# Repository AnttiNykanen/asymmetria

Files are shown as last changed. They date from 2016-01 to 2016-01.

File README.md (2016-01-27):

# ESP8266-based LED dimmer #

This dimmer designed to fit inside a Lival Asymmetria desk lamp. The
plan is to use [LED strips like these][ledstrips] to replace the stock
fluorescent bulb, but other kinds of LEDs should work too, as long as
you adjust the shunt resistor accordingly and don't exceed the 3.3V
regulator's ratings.

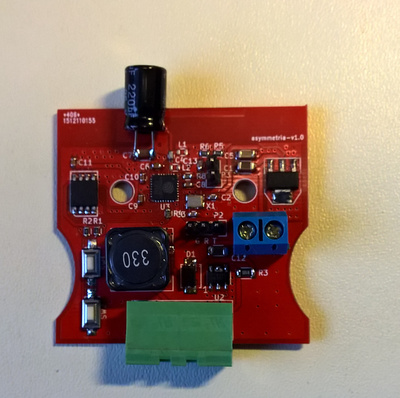
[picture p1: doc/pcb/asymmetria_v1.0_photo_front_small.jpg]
pcb photo


## Contents of this directory ##

  * [hardware](./hardware/): Hardware design files
  * [firmware](./firmware/): Firmware source code
  * [doc](./doc/): Documentation
  
## License ##

  * Hardware:
    [CC BY-SA 4.0](https://creativecommons.org/licenses/by-sa/4.0/)
  * Firmware:
    * Files in the user subdirectory:
      [ISC](https://opensource.org/licenses/ISC)
    * Everything else: whatever the files say
 
## The Fine Print ##

Note that owning and/or using homemade radio transmitters, which this thing is, might not be legal for everyone everywhere.

[ledstrips]: http://www.aliexpress.com/item/Ultra-thin-5W-LED-COB-60-Chip-Led-Driving-DRL-Daytime-Running-Light-Lamp-Bar-Strip/32303226004.html

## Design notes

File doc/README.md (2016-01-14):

Contents of the doc directory:

  * [bom](./bom/): Bill of Materials
  * [doxygen](./doxygen/): Source code documentation
  * [pcb](./pcb/): PCB renders and photos
  * [schematic](./schematic/): Schematic PDF

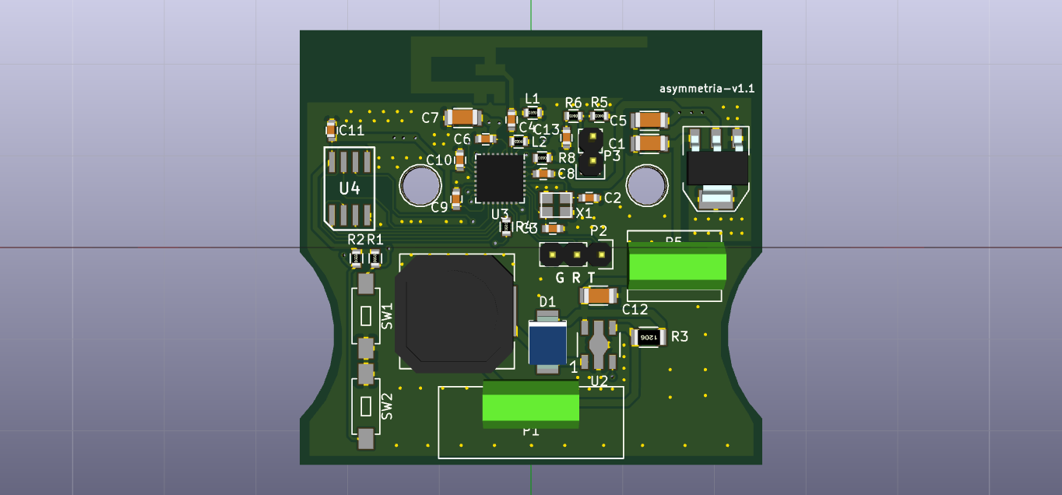
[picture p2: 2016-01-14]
doc/pcb/asymmetria_v1.1_render_front.png

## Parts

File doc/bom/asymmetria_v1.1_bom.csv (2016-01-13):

V1.1 BOM
Reference | Value | Footprint | Manufacturer | Mfg P/N
U3 | ESP8266EX | Housings_DFN_QFN:QFN-32-1EP_5x5mm_Pitch0.5mm | Espressif | ESP8266EX
C1 | 10uF | Capacitors_SMD:C_1206 | Yageo | CC1206KKX7R8BB106
C5 | 22uF | Capacitors_SMD:C_1206 | Yageo | CC1206KKX7R6BB226
R8 | 12K | Resistors_SMD:R_0603 | Vishay/Dale | CRCW060312K0FKEA
C6 | 0.1uF | Capacitors_SMD:C_0603 | Yageo | CC0603KRX7R9BB104
C7 | 100uF | Capacitors_SMD:C_1206 | Yageo | CC1206MKX5R5BB107
C8 | 0.1uF | Capacitors_SMD:C_0603 | Yageo | CC0603KRX7R9BB104
X1 | 26MHz 10ppm 3x2.5mm | Crystals_Oscillators_SMD:crystal_FA238-TSX3225 | Epson Timing | TSX-3225 26.0000MF09Z-AC3
C2 | 10pF | Capacitors_SMD:C_0603 | Yageo | CC0603GRNPO9BN100
C3 | 10pF | Capacitors_SMD:C_0603 | Yageo | CC0603GRNPO9BN100
C10 | 0.1uF | Capacitors_SMD:C_0603 | Yageo | CC0603KRX7R9BB104
ANT1 | ANTENNA | umetronics:PCB_IF_ANT_2.4G | NA | NA
L1 | NC | Resistors_SMD:R_0603 | NA | NA
L2 | NC | Resistors_SMD:R_0603 | NA | NA
C4 | 5.6pF C0G | Capacitors_SMD:C_0603 | Yageo | CC0603CRNPO9BN5R6
SW1 | 3x6x2.5mm | Buttons_Switches_SMD:SW_SPST_EVQPE1 | TE Connectivity | FSMSM
R1 | 10k | Resistors_SMD:R_0603 | Vishay/Dale | CRCW060310K0FKEA
SW2 | 3x6x2.5mm | Buttons_Switches_SMD:SW_SPST_EVQPE1 | TE Connectivity | FSMSM
R2 | 10k | Resistors_SMD:R_0603 | Vishay/Dale | CRCW060310K0FKEA
U4 | W25Q32FV | umetronics:SOIC-8-208 | Winbond | W25Q32FVSSIG
C11 | 0.1uF | Capacitors_SMD:C_0603 | Yageo | CC0603KRX7R9BB104
R4 | 220R | Resistors_SMD:R_0603 | Vishay/Dale | CRCW0603220RFKEA
U2 | PT4115B89E | Housings_SOT-89:SOT89-5_Housing | PowTech | PT4115B89E
R3 | 0R1 | Resistors_SMD:R_1206 | Yageo | PT1206FR-070R1L
D1 | SS24 | Diodes_SMD:SMB_Standard | ON Semiconductor | SS24T3G
L3 | 33uH | Choke_SMD:Choke_SMD_12x12mm_h8mm | TDK | B82477G4333M
C12 | 10uF | Capacitors_SMD:C_1206 | Yageo | CC1206KKX7R8BB106
P1 | CONN_01X02 | umetronics:5EHDRM-02P | Dinkle | 5EHDRM-02P
P2 | CONN_01X03 | Pin_Headers:Pin_Header_Straight_1x03 | TE Connectivity | 4-103321-5
P3 | CONN_01X02 | Pin_Headers:Pin_Header_Straight_1x02 | TE Connectivity | 5-146278-2
R5 | 4k7 | Resistors_SMD:R_0603 | Vishay/Dale | CRCW06034K70FKEA
R6 | 4k7 | Resistors_SMD:R_0603 | Vishay/Dale | CRCW06034K70FKEA
C13 | 0.1uF | Capacitors_SMD:C_0603 | Yageo | CC0603KRX7R9BB104
P5 | CONN_01X02 | Connect:bornier2 | TE Connectivity | 282837-2
C9 | 0.1uF | Capacitors_SMD:C_0603 | Yageo | CC0603KRX7R9BB104
U1 | AMS1117-3.3 | TO_SOT_Packages_SMD:SOT-223 | Advanced Monolithic Systems | AMS1117-3.3
 |  | 15mm dia switch

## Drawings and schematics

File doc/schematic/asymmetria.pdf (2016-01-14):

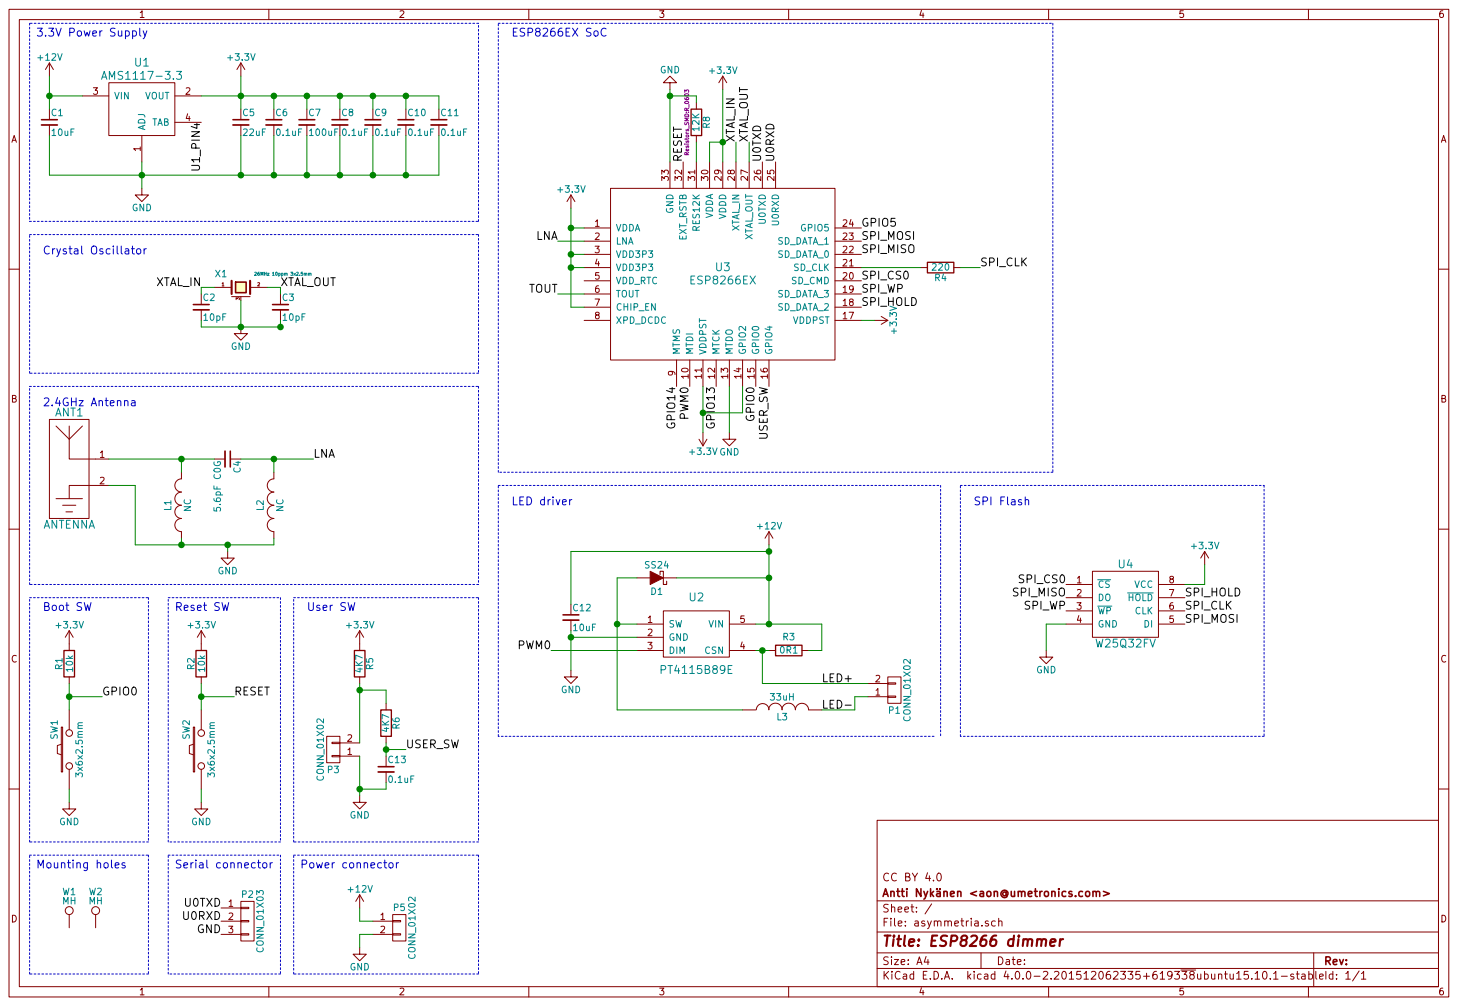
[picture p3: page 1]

9 MTDI 10 SD_CMD 20 VDDA 30 VDDPST 11 SD_CLK 21 RES12K 31 MTCK 12 SD_DATA_0 22 EXT_RSTB 32 MTDO 13 SD_DATA_1 23 GND 33 GPIO2 14 GPIO5 24 GPIO0 15 U0RXD 25 GPIO4 16 U0TXD 26 VDDPST 17 XTAL_OUT 27 SD_DATA_2 18 XTAL_IN 28 SD_DATA_3 19 VDDD 29 U3 ESP8266EX

File: asymmetria.sch Sheet: / Antti Nykänen <aon@umetronics.com> CC BY 4.0

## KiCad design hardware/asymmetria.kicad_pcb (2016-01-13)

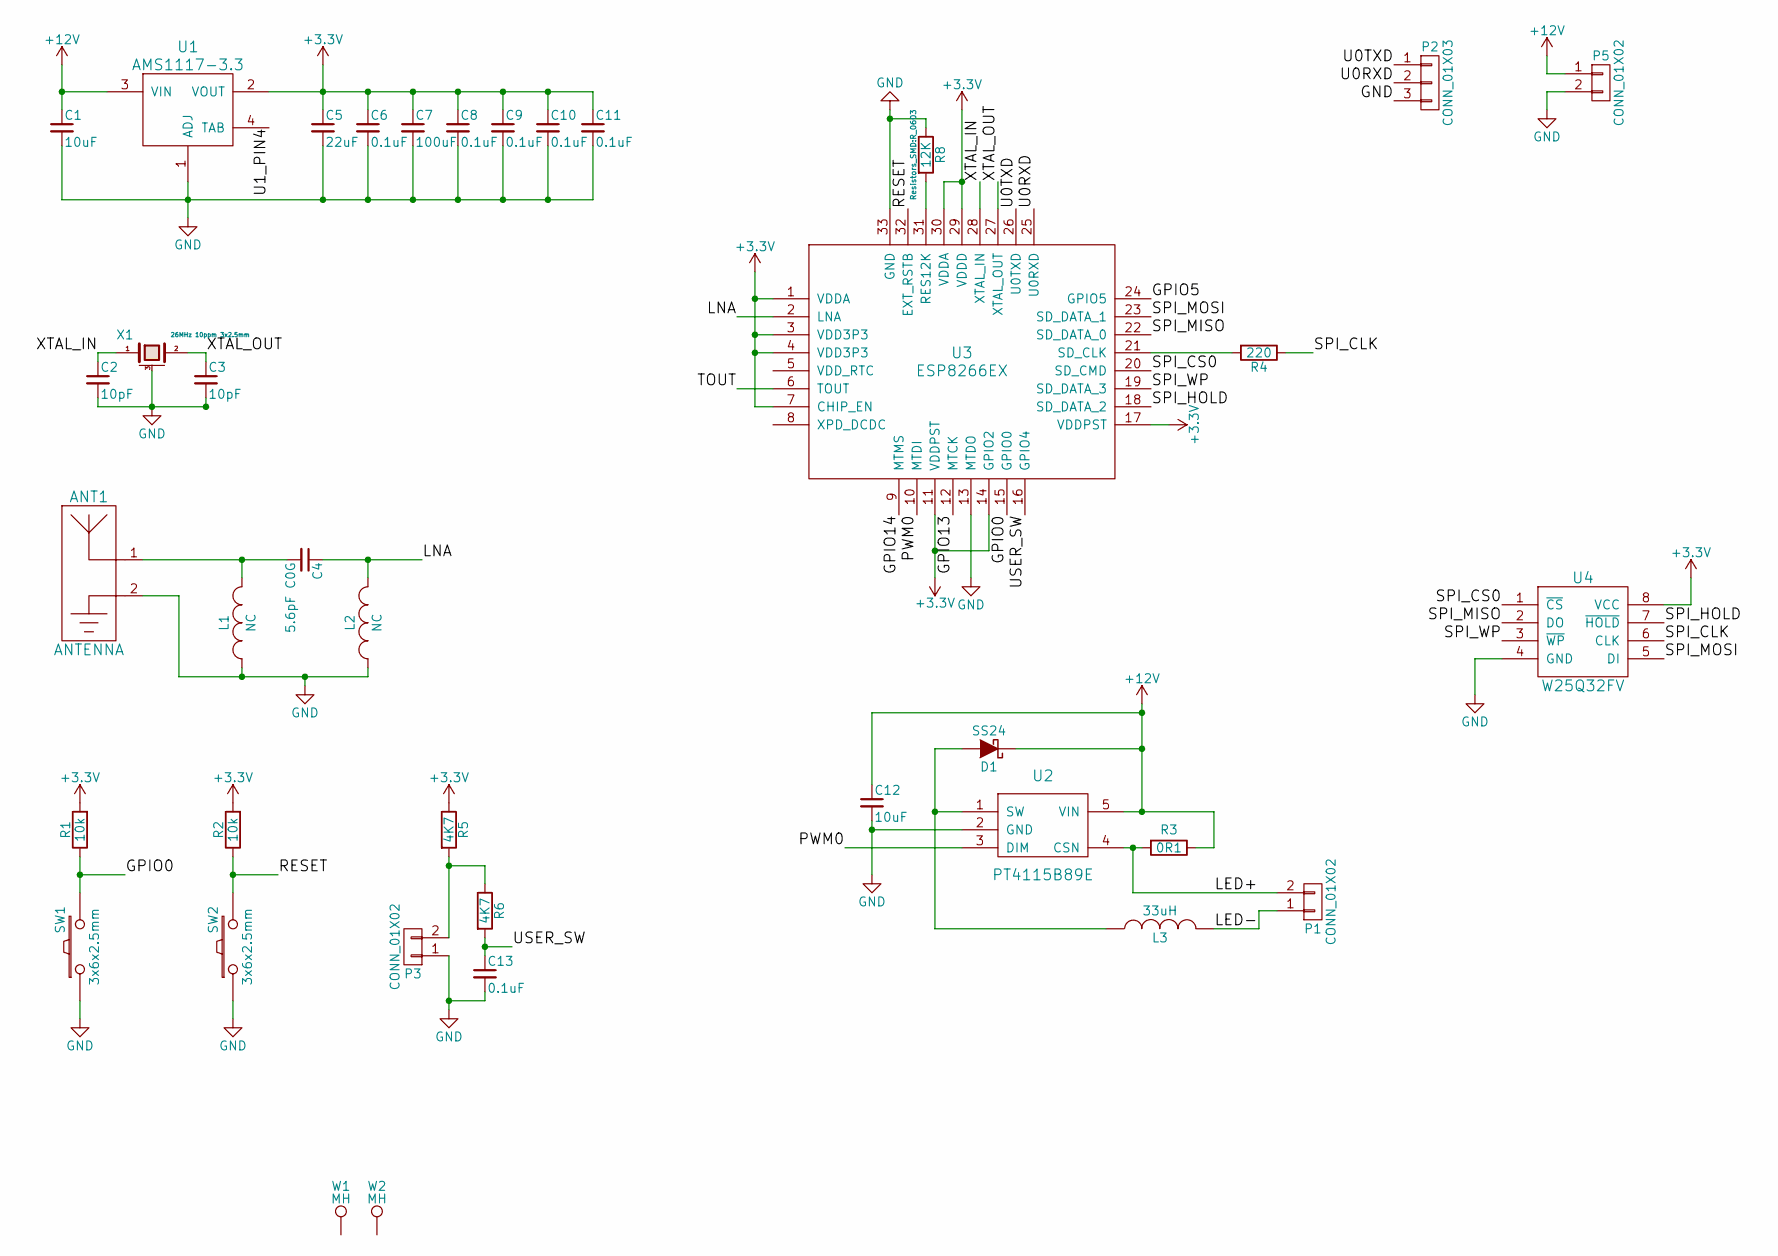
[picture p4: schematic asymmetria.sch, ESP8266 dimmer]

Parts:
ANT1: ANTENNA; PCB_IF_ANT_2.4G
C1, C12: 10uF; C_1206
C2, C3: 10pF; C_0603
C4: 5.6pF C0G; C_0603
C5: 22uF; C_1206
C6, C8, C9, C10, C11, C13: 0.1uF; C_0603
C7: 100uF; C_1206
D1: SS24; SMB_Standard
L1, L2: NC; R_0603
L3: 33uH; Choke_SMD_12x12mm_h8mm
P1: CONN_01X02; 5EHDRM-02P
P2: CONN_01X03; Pin_Header_Straight_1x03
P3: CONN_01X02; Pin_Header_Straight_1x02
P5: CONN_01X02; bornier2
R1, R2: 10k; R_0603
R3: 0R1; R_1206
R4: 220; R_0603
R5, R6: 4K7; R_0603
R8: 12K; R_0603
SW1, SW2: 3x6x2.5mm; SPST_3x6x2.5_SMD
U1: AMS1117-3.3; SOT-223
U2: PT4115B89E; SOT89-5_Housing
U3: ESP8266EX; QFN-32-1EP_5x5mm_Pitch0.5mm
U4: W25Q32FV; SOIC-8-208
W1, W2: MH; 1pin
X1: 26MHz 10ppm 3x2.5mm; crystal_FA238-TSX3225

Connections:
+3V3: C5.1, C6.1, C7.1, C8.1, C9.1, C10.1, C11.1, R1.2, R2.2, R5.1, U1.2 (VOUT), U3.1 (VDDA), U3.3 (VDD3P3), U3.4 (VDD3P3), U3.7 (CHIP_EN), U3.11 (VDDPST), U3.14 (GPIO2), U3.17 (VDDPST), U3.29 (VDDD), U3.30 (VDDA), U4.8 (VCC)
+12V: C1.1, C12.1, D1.1 (K), P5.1, R3.1, U1.3 (VIN), U2.5 (VIN)
/GPIO0: R1.1, SW1.2, U3.15 (GPIO0)
/GPIO5: U3.24 (GPIO5)
/GPIO13: U3.12 (MTCK)
/GPIO14: U3.9 (MTMS)
/LED+: P1.2, R3.2, U2.4 (CSN)
/LED-: L3.2, P1.1
/LNA: C4.1, L2.2, U3.2 (LNA)
/PWM0: U2.3 (DIM), U3.10 (MTDI)
/RESET: R2.1, SW2.2, U3.32 (EXT_RSTB)
/SPI_CLK: R4.1, U4.6 (CLK)
/SPI_CS0: U3.20 (SD_CMD), U4.1 (~CS)
/SPI_HOLD: U3.18 (SD_DATA_2), U4.7 (~HOLD)
/SPI_MISO: U3.22 (SD_DATA_0), U4.2 (DO)
/SPI_MOSI: U3.23 (SD_DATA_1), U4.5 (DI)
/SPI_WP: U3.19 (SD_DATA_3), U4.3 (~WP)
/TOUT: U3.6 (TOUT)
/U0RXD: P2.2, U3.25 (U0RXD)
/U0TXD: P2.1, U3.26 (U0TXD)
/U1_PIN4: U1.4 (TAB)
/USER_SW: C13.1, R6.2, U3.16 (GPIO4)
/XTAL_IN: C2.1, U3.28 (XTAL_IN), X1.1
/XTAL_OUT: C3.1, U3.27 (XTAL_OUT), X1.2
GND: ANT1.2, C1.2, C2.2, C3.2, C5.2, C6.2, C7.2, C8.2, C9.2, C10.2, C11.2, C12.2, C13.2, L1.1, L2.1, P2.3, P3.1, P5.2, R8.1, SW1.1, SW2.1, U1.1 (ADJ), U2.2 (GND), U3.13 (MTDO), U3.33 (GND), U4.4 (GND), X1.3 (case)
unnamed: ANT1.1, C4.2, L1.2
unnamed: D1.2 (A), L3.1, U2.1 (SW)
unnamed: P3.2, R5.2, R6.1
unnamed: R4.2, U3.21 (SD_CLK)
unnamed: R8.2, U3.31 (RES12K)

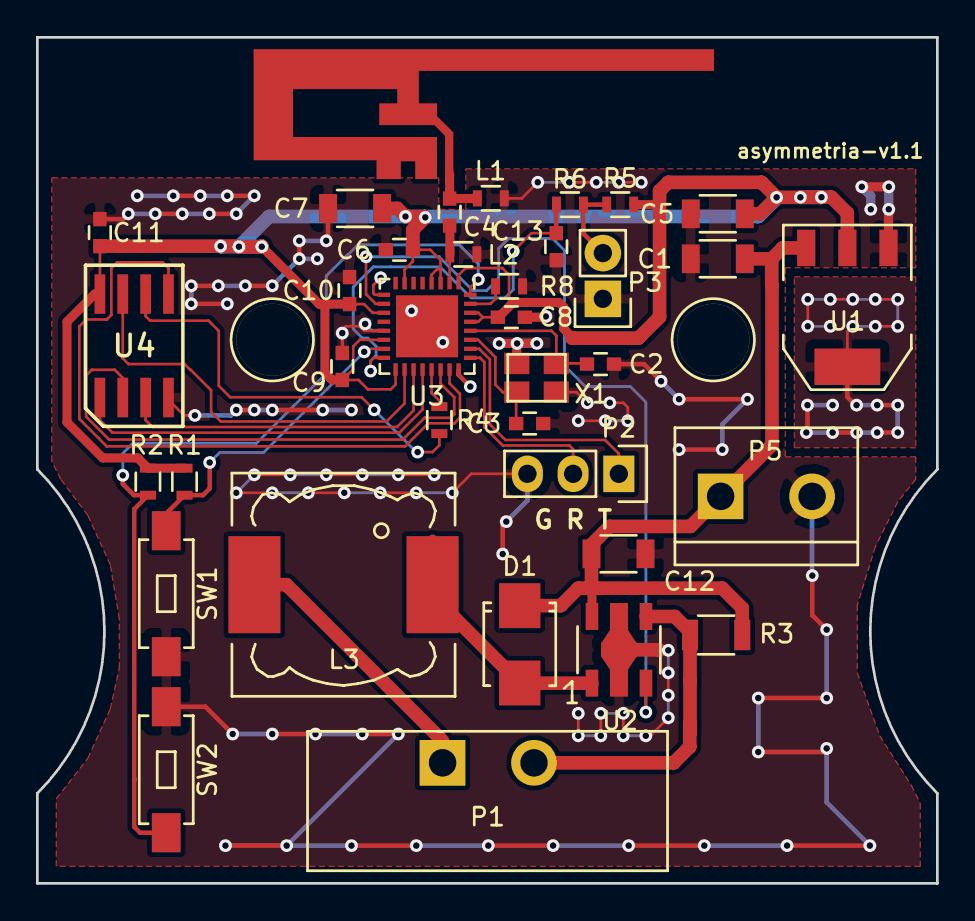
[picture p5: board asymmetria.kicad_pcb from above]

Board: 2 copper layers, 50.0 x 47.0 mm, 38 parts (0 on the bottom side), 25 nets.

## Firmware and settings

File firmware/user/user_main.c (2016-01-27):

/*
 * ESPRSSIF MIT License
 *
 * Copyright (c) 2015 <ESPRESSIF SYSTEMS (SHANGHAI) PTE LTD>
 *
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
 */

/**
 * @file user_main.c
 * @brief User application main file
 */

#include "esp_common.h"
#include "driver/uart.h"

#include "httpd.h"
#include "httpdespfs.h"
#include "espfs.h"
#include "webpages-espfs.h"
#include "auth.h"

#include "user_cgi.h"
#include "user_dimmer.h"
#include "user_button.h"

/** HTTP authentication username */
#define AUTH_USER "testaaja"

/** HTTP authentication password */
#define AUTH_PASS "testi"

/** Wi-Fi SSID */
#define AP_SSID "ESP8266"

/** Wi-Fi Password */
#define AP_PASSWORD "none"

/** Wi-Fi Authentication mode */
#define AP_AUTHMODE AUTH_OPEN

/** Wi-Fi Soft-AP channel */
#define AP_CHANNEL 5

/**
 * HTTP authentication function
 */
int authGetUserPw(HttpdConnData *connData, int no, char *user, int userLen, char *pass, int passLen) {
    int rv = 0;
    
    if (no == 0) {
        strncpy(user, AUTH_USER, userLen);
        strncpy(pass, AUTH_PASS, passLen);
        rv = 1;
    }

    return rv;
}

/** HTTPD routes */
HttpdBuiltInUrl g_builtInUrls[] = {
    {"*", authBasic, authGetUserPw },
    {"/", cgiRedirect, "/index.html"},
    {"/setStatus", user_cgi_set_status, NULL },
    {"/setDimmer", user_cgi_set_dimmer, NULL },
    {"/getDimmer", user_cgi_get_dimmer, NULL },
    {"*", cgiEspFsHook, NULL},
    {NULL, NULL, NULL}
};


/**
 * Entry of user application, init user function here
 */
void user_init(void)
{
    UART_ConfigTypeDef uart_config;
    struct softap_config *config;
    dimmer_status_t *dim_initial_status;

    /* Set UART0 to 115200 bps, 8N1 */
    uart_config.baud_rate = BIT_RATE_115200;
    uart_config.data_bits = UART_WordLength_8b;
    uart_config.parity = USART_Parity_None;
    uart_config.stop_bits = USART_StopBits_1;
    uart_config.flow_ctrl = USART_HardwareFlowControl_None;
    uart_config.UART_RxFlowThresh = 120;
    uart_config.UART_InverseMask = UART_None_Inverse;

    UART_ParamConfig(UART0, &uart_config);

    /* Configure Wi-Fi */
    wifi_set_opmode(SOFTAP_MODE);
    
    config = (struct softap_config *)zalloc(sizeof(struct softap_config));
    wifi_softap_get_config(config);
    sprintf(config->ssid, AP_SSID);
    sprintf(config->password, AP_PASSWORD);
    config->authmode = AP_AUTHMODE;
    config->ssid_len = 0;
    config->max_connection = 4;
    config->channel = AP_CHANNEL;
    wifi_softap_set_config(config);
    free(config);

    /* Start httpd task */
    espFsInit((void*)webpages_espfs_start);
    httpdInit(g_builtInUrls, 80);

    /* Start dimmer task */
    dim_initial_status = (dimmer_status_t *)zalloc(sizeof(dimmer_status_t));
    dim_initial_status->power_on = true;
    dim_initial_status->dim_pct  = 85;
    dimmer_init(dim_initial_status, 50, 0);
    free(dim_initial_status);

    /* Start button task */
    button_init();
}

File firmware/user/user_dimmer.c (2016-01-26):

/**
 * @file  user_dimmer.c
 * @brief PT4115 dimmer control
 * 
 * @author Antti Nykänen <aon@umetronics.com>
 */

#include "esp_common.h"

#include "freertos/FreeRTOS.h"
#include "freertos/semphr.h"
#include "freertos/task.h"
#include "freertos/queue.h"

#include "user_dimmer.h"

static xSemaphoreHandle s_status_mutex;
static dimmer_status_t s_status;

static xQueueHandle s_dimmer_queue;

static uint32_t s_pwm_period;

static uint8_t s_pwm_channel;

static uint8_t s_initialized = 0;

static const uint32_t DIMMER_QUEUE_MSG = 0x55;

uint32 pwm_init_info[1][3]={
    {PERIPHS_IO_MUX_MTDI_U, FUNC_GPIO12, 12}
};

uint32 pwm_init_dcs[1] = {0x00};

/**
 * Convert duty cycle percentaget to actual duty cycle value
 *
 * @param  pct duty cycle percentage
 *
 * @return scaled duty cycle value 
 */
static uint32_t s_dimmer_pct_to_dc(uint8_t pct)
{
    if (pct > 100)
        pct = 100;

    /*
     * TODO: investigate why the formula in the docs gives incorrect
     * results but this seems to work more or less correctly
     */
    return (s_pwm_period * 10 * pct / 50);
}

/**
 * Get dimmer status
 *
 * @param status structure where the current status is to be placed
 */
void dimmer_get_status(dimmer_status_t *status)
{
    xSemaphoreTake(s_status_mutex, portMAX_DELAY);
    status->power_on = s_status.power_on;
    status->dim_pct = s_status.dim_pct;
    xSemaphoreGive(s_status_mutex);
}

/**
 * Set dimmer status
 *
 * @param status structure where the status is to be read from
 */
void dimmer_set_status(dimmer_status_t *status)
{
    xSemaphoreTake(s_status_mutex, portMAX_DELAY);
    s_status.dim_pct = status->dim_pct;
    s_status.power_on = status->power_on;
    xQueueSend(s_dimmer_queue, &DIMMER_QUEUE_MSG, 0);
    xSemaphoreGive(s_status_mutex);
}

/**
 * Set dimmer percentage
 *
 * @param dim_pct dim percentage
 */
void dimmer_set_dim_pct(uint8_t dim_pct)
{
    xSemaphoreTake(s_status_mutex, portMAX_DELAY);
    s_status.dim_pct  = dim_pct;
    xSemaphoreGive(s_status_mutex);
    xQueueSend(s_dimmer_queue, &DIMMER_QUEUE_MSG, 0);
}

/**
 * Get dimmer percentage
 *
 * @return dimmer percentage (0-100)
 */
uint8_t dimmer_get_dim_pct(void)
{
    uint8_t rv;
    xSemaphoreTake(s_status_mutex, portMAX_DELAY);
    rv = s_status.dim_pct;
    xSemaphoreGive(s_status_mutex);
    return rv;
}


/**
 * Set power on or off
 *
 * @param power_on whether to set the power on or off
 */
void dimmer_set_power_on(bool power_on)
{
    xSemaphoreTake(s_status_mutex, portMAX_DELAY);
    s_status.power_on = power_on;
    xSemaphoreGive(s_status_mutex);
    xQueueSend(s_dimmer_queue, &DIMMER_QUEUE_MSG, 0);
}

/**
 * Get power status
 *
 * @return power status (true=on, false=off)
 */
bool dimmer_get_power_on(void)
{
    bool rv;
    xSemaphoreTake(s_status_mutex, portMAX_DELAY);
    rv = s_status.power_on;
    xSemaphoreGive(s_status_mutex);
    return rv;
}

/**
 * Dimmer FreeRTOS task
 *
 * @param parameters task parameters
 */
static void dimmer_task(void *parameters)
{
    portBASE_TYPE recv_status;
    portBASE_TYPE recv_value;

    printf("Dimmer: task created\r\n");
    
    while (1) {
        recv_status = xQueueReceive(s_dimmer_queue, &recv_value, portMAX_DELAY);
        
        if (recv_status == pdPASS) {
            if (recv_value & DIMMER_QUEUE_MSG) {
                printf("Dimmer: received update notification\r\n");

                xSemaphoreTake(s_status_mutex, portMAX_DELAY);
                if (s_status.power_on == true) {
                    pwm_set_duty(s_dimmer_pct_to_dc(s_status.dim_pct), s_pwm_channel);
                } else {
                    pwm_set_duty(0, s_pwm_channel);
                }
                xSemaphoreGive(s_status_mutex);
                
                pwm_start();
            }
        }
    }
}

/**
 * Initialize the dimmer and start the RTOS task
 *
 * @param initial_status  initial dimmer status structure
 * @param pwm_period      PWM period
 * @param pwm_channel_num PWM channel number
 */
void dimmer_init(dimmer_status_t *initial_status, uint32_t pwm_period,
                 uint32_t pwm_channel_num)
{
    /* There can be only one task, so return if already initialized. */
    if (s_initialized)
        return;

    /* Create status mutex */
    s_status_mutex = xSemaphoreCreateMutex();

    /* Create notification message queue */
    s_dimmer_queue = xQueueCreate(5, sizeof(dimmer_status_t));
    
    s_pwm_period = pwm_period;

    /* Initialize status struct */
    s_status.power_on = initial_status->power_on;
    s_status.dim_pct = initial_status->dim_pct;

    /* Init PWM */
    s_pwm_channel = pwm_channel_num;

    if (s_status.power_on == true) {
        pwm_init_dcs[0] = s_dimmer_pct_to_dc(s_status.dim_pct);
    }

    pwm_init(pwm_period, pwm_init_dcs, 1, pwm_init_info);
    pwm_start();

    printf("Dimmer: PWM initialized and started\r\n");

    printf("Ch0 DC: %d\r\n", pwm_get_duty(0));
    printf("Period: %d\r\n", pwm_get_period());

    /* Create dimmer task */
    xTaskCreate(dimmer_task, "Dimmer", configMINIMAL_STACK_SIZE,
                NULL, 3, NULL);

    /* Prevent further intialization */
    s_initialized = 1;
}

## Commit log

2015-11-21 initial revision
    [asymmetria.kicad_pcb, asymmetria.sch, asymmetria_bom.csv]
2015-12-04 component checks
    [asymmetria.kicad_pcb, asymmetria.sch]
2015-12-14 beginnings of firmware, gerbers for hardware
    [asymmetria.kicad_pcb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]
2015-12-15 button ui
2015-12-15 added debounce resistor values
    [asymmetria.sch]
2016-01-13 grounded qfn center pad, increased C7 to 100uF
    [asymmetria.kicad_pcb, asymmetria.sch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]
2016-01-13 updated drill file
2016-01-13 moved bom to doc, added doxyfile
    [asymmetria_bom.csv, asymmetria_v1.1_bom.csv]
2016-01-13 PCB photo
2016-01-14 group schematic into sections
    [asymmetria.sch]
2016-01-26 changed pwm frequency

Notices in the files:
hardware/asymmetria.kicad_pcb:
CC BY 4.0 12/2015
